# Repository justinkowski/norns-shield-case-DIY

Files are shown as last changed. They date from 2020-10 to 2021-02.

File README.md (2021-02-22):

# norns-shield-diy-case
DIY case inspired by the original Monome Norns

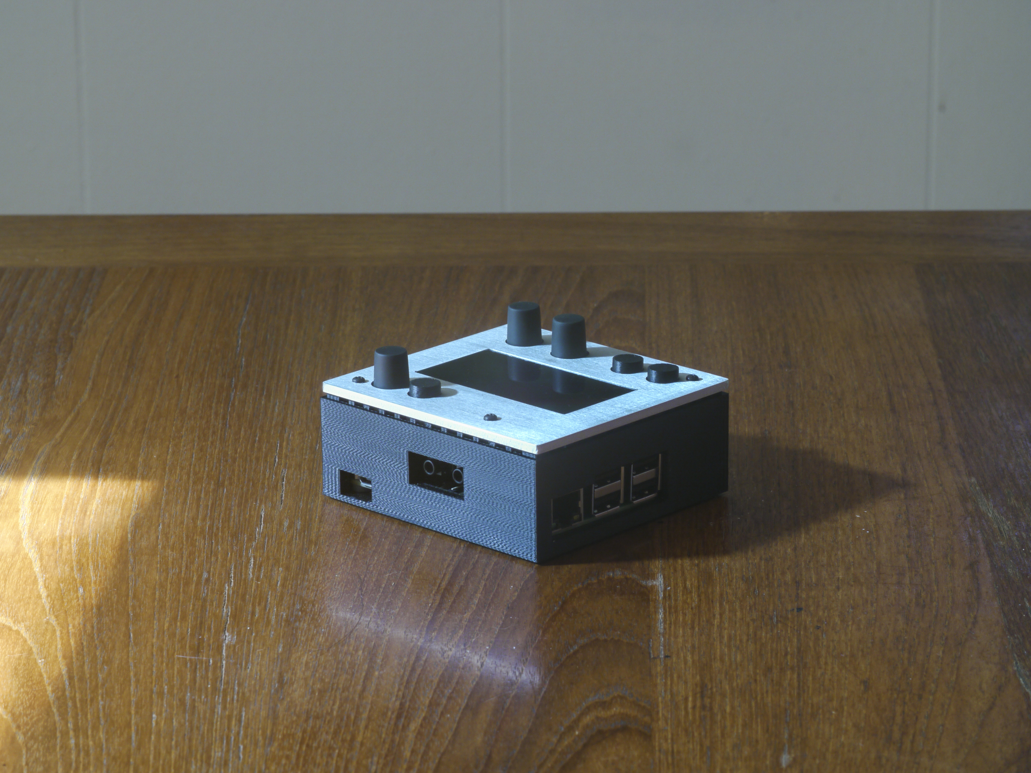
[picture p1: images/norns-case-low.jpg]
Norns Shield with Case


#### The case is made of three parts:
* A laser-cut top panel
* A 3D-printed shell
* A polycarbonate window for the OLED (OPTIONAl)

#### EDIT Feb 2021: Added an alternate version of the top panel that fits the case that now ships with the shield.

I chose to have a top panel made out of aluminum as a nod to the original Norns, but any flat material will work. If you want an aluminum version for yourself I have some extras for sale here: https://rvrb.io/2020-aluminum-top-19qjma

The shell includes hidden ventilation slots around the top lip and on the bottom face, and is optimized to print with minimal supports. The polycarbonate window is not necessary, but looks nice, especially in smoked acrylic. The OLED window is a simple rectangle, so you could cut it yourself to save money over laser cutting. 

#### All of the hardware for the original Norns Shield case can be used. 
* The previous version of this case required 3D-printed buttons, it can now use the buttons and knobs included with the kit.
* If you'd like to use an aftermarket knob, any with diameter <12mm will work.

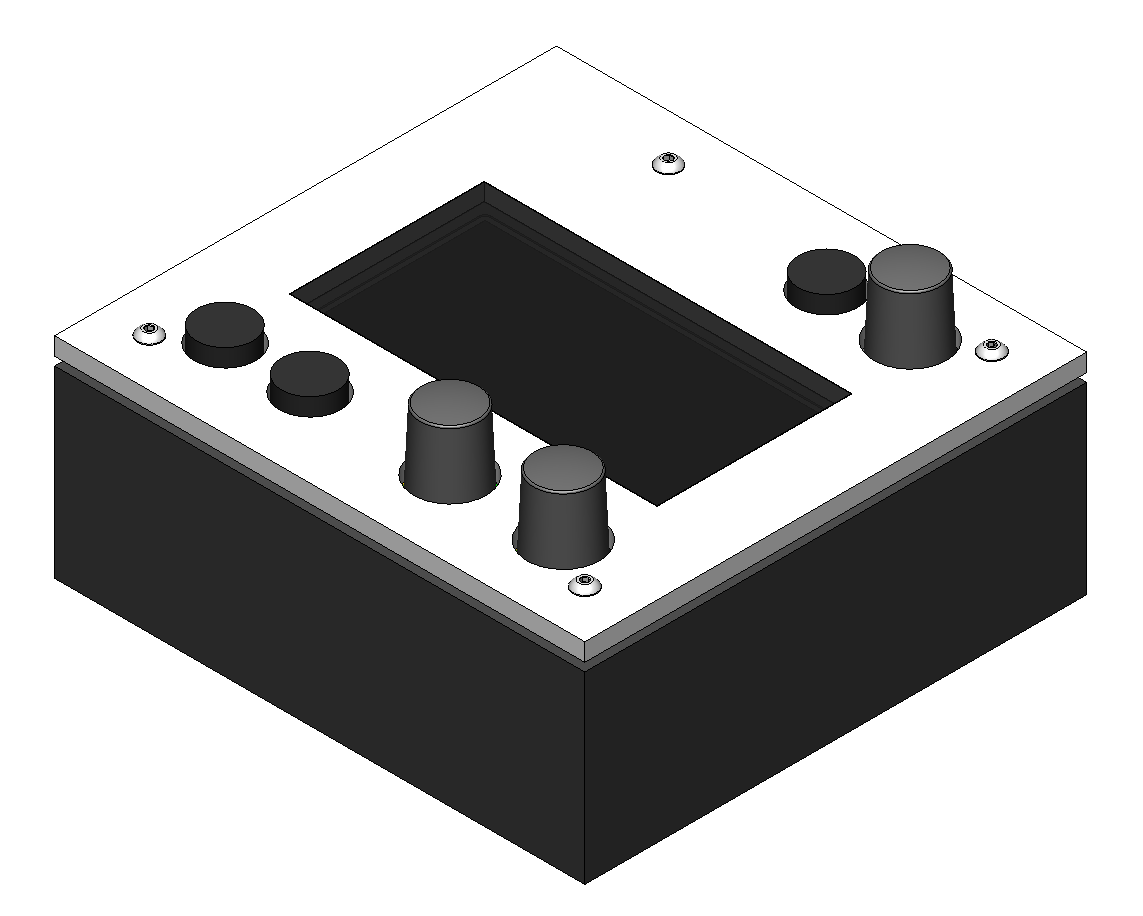
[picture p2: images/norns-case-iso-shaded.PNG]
Norns Shield with Case


### Assembly Details
* If you've already built your Norns Shield, dissasemble the case and discard the 2 plastic spacers from beneath the RPi. Reserve all other hardware
* Lower the Pi+Shield assembly down into the shell. Take care not to damage the SD card holder. It is a tight fit, but it should work with some patience.
* Loosely install the 4 screws on the bottom of the shell to hold it in place. Do not tighten fully yet.
* If you have made a window for the screen, you can attach it to the top panel with some clear packing tape on the underside. Just work slowly and make sure both parts are free from dust to avoid bubbles.
* Make sure your buttons and knobs are already installed, then place the top panel+window assembly on the shield and loosely install the remaining screws.
* Adjust the positioning of the top panel so  the buttons and knobs move freely, then tighten the top screws.
* Adjust the positioning of the bottom shell to align the edges with the top panel, then tighten the bottom screws.

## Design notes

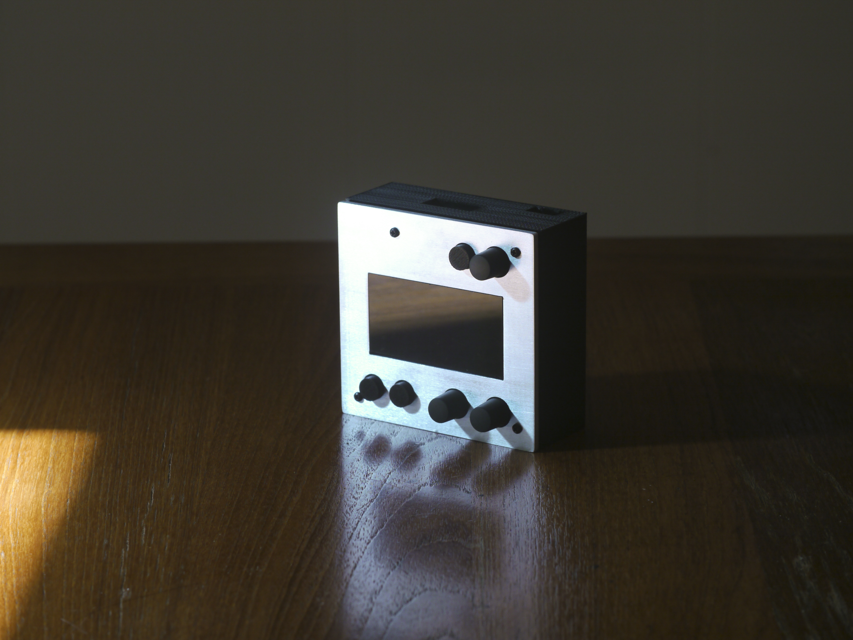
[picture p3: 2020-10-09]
images/norns-case-front.jpg

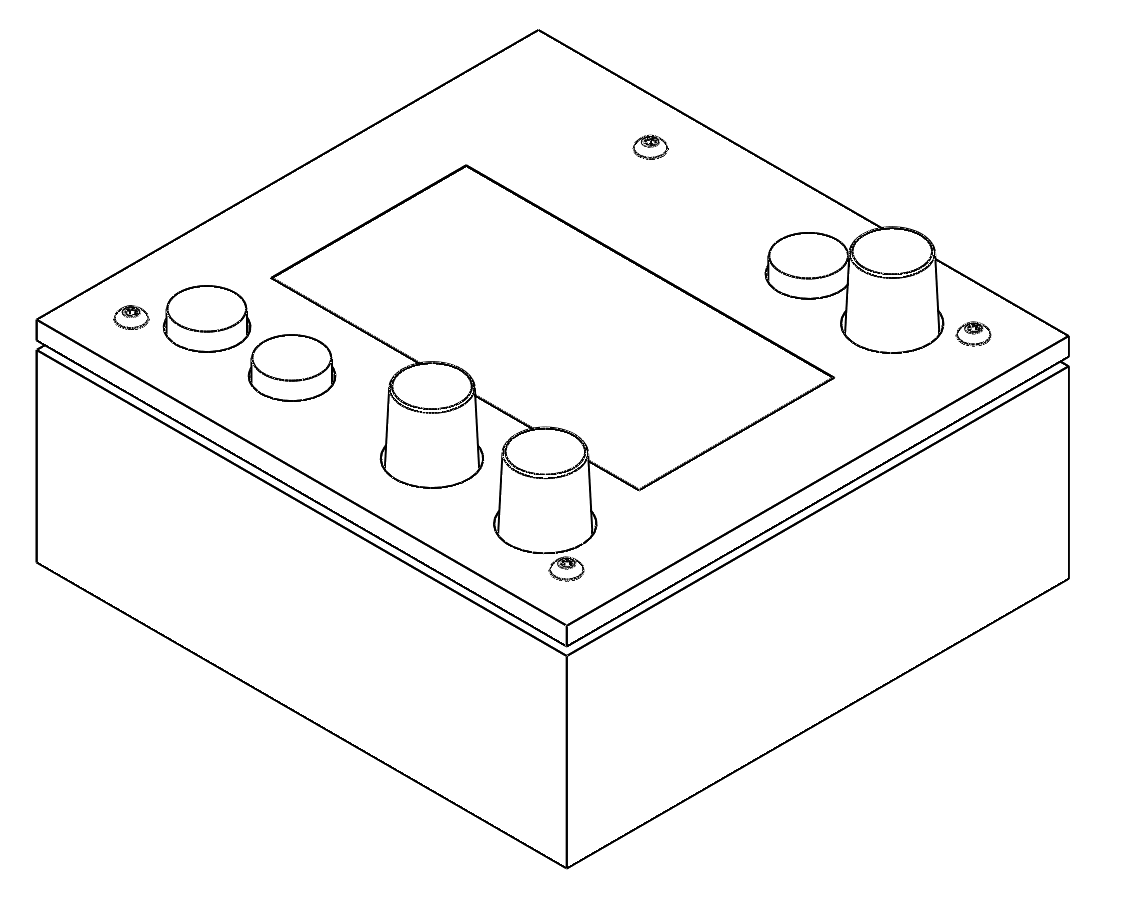
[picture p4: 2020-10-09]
images/norns-case-iso.PNG

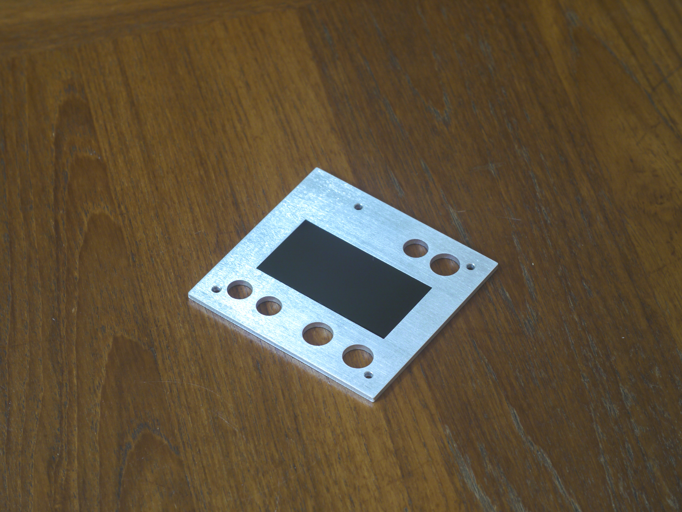
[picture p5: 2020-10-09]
images/norns-case-panel.jpg

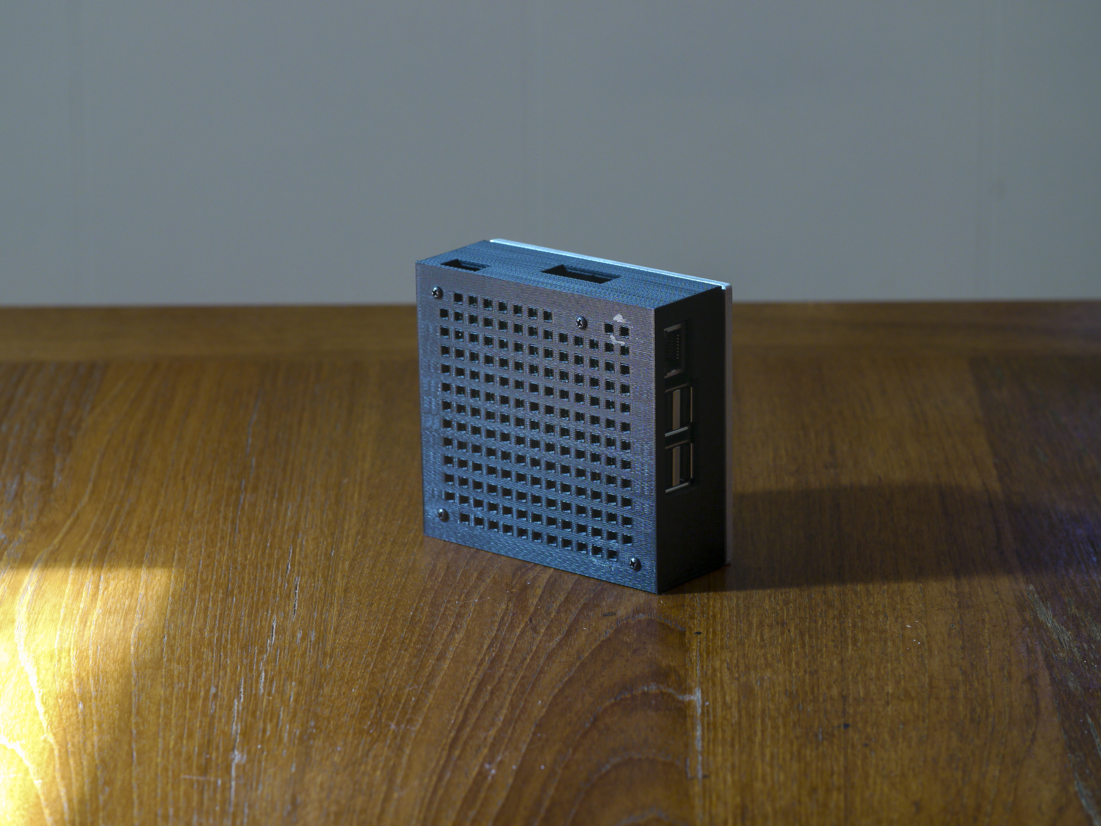
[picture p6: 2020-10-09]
images/norns-case-bottom.jpg

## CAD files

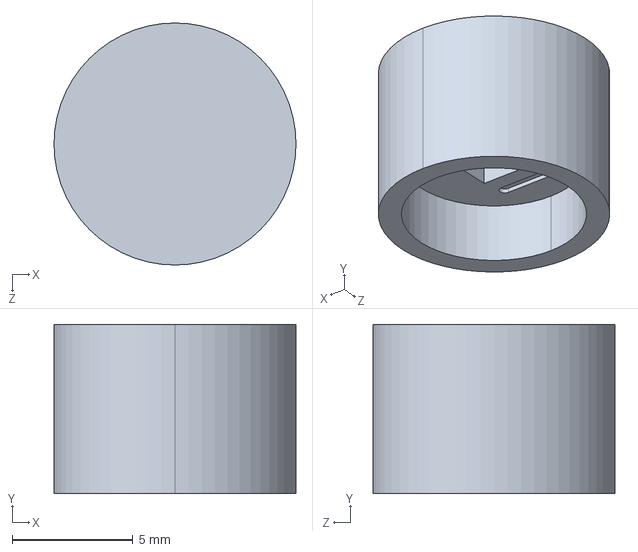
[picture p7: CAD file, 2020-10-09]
Low Profile Keycap/BTN CAP PVA.STEP
10.0 x 7.00 x 10.0 mm

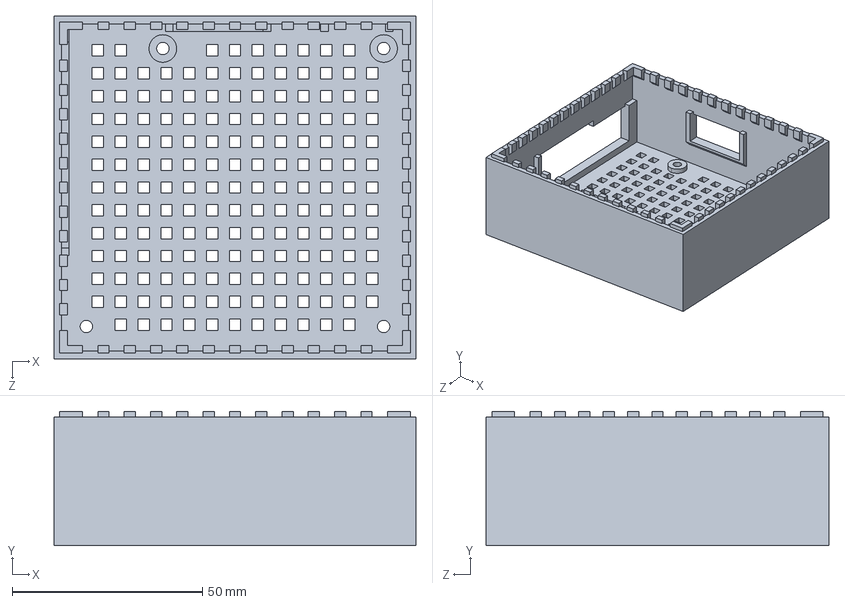
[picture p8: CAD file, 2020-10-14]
Shell/NORNS-SHIELD-CASE-SHELL.STEP
95.1 x 35.3 x 90.0 mm

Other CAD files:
Low Profile Keycap/BTN CAP PVA.STL
Shell/NORNS-SHIELD-CASE-SHELL.STL

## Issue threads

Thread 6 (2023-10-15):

hardware bom should be added

jmej, 2023-10-15:
I see "All of the hardware for the original Norns Shield case can be used."

Is that the same list as is on the current readme here?
https://github.com/monome/norns-shield
I think it may have been revised at some point...

I don't want to make a pull request because I'm not sure if this is right... but this is what is currently listed on the norns shield github. If someone can confirm it would be great to throw it into the readme of this repo

2 Female Threaded Hex Standoff Aluminum, 3/16" Hex, 5/16" Long, 2-56 Thread 91780A104
2 Female Threaded Hex Standoff Aluminum, 3/16" Hex, 5/8" Long, 2-56 Thread 91780A111
2 Female Threaded Hex Standoff Aluminum, 3/16" Hex, 3/4" Long, 2-56 Thread 91780A113
4 Male-Female Threaded Hex Standoff Aluminum, 3/16" Hex Size, 1/2" Long, 2-56 Thread Size 93505A213
4 Off-White Nylon Unthreaded Spacer 1/4" OD, 3/32" Long, for Number 6 Screw Size 94639A247
8 Black-Oxide 18-8 Stainless Steel Pan Head Phillips Screws 2-56 Thread, 1/4" Long 91249A050
2 Black-Oxide 18-8 Stainless Steel Pan Head Phillips Screws 2-56 Thread, 3/8" Long 91249A054

jmej, 2023-10-15:
Similarly it would be nice to have part numbers for compatible button and knob caps. Not seeing that anywhere on the norns-shield github...

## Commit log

2021-02-22 Add files via upload
    add alternate version for JustinCHC case
2021-02-22 Update README.md
    add note about JustinCHC case panel
2021-02-22 Add files via upload
    Add files for JustinCHC case
